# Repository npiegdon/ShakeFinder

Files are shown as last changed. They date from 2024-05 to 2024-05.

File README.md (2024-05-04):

# ShakeFinder
## A low-cost, high-sensitivity vibration sensor

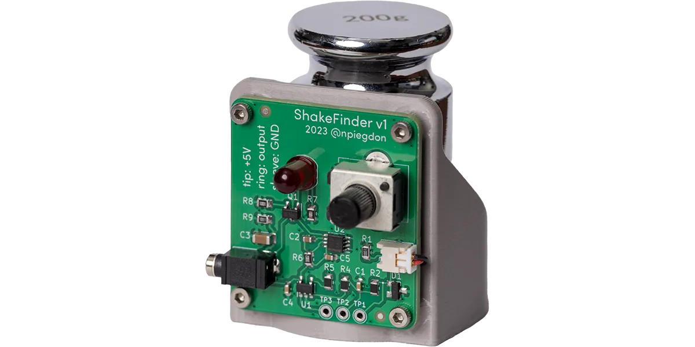
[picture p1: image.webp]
ShakeFinder (https://www.youtube.com/watch?v=hmemnF16wfw)


**Watch the [design video](https://www.youtube.com/watch?v=hmemnF16wfw) on YouTube!**

ShakeFinder is based on [David Houlding's](https://davidhoulding.blogspot.com/2014/02/high-sensitivity-vibration-sensor-using.html) vibration sensor with a number of improvements.  The most notable is an open-drain output so it can be connected to non-5V microcontrollers (like Raspberry Pi) easily.

This sensor was created for use with my homemade 8mm film scanner, the [ReelSlow8](https://forums.kinograph.cc/t/the-reelslow8-film-scanner/2491).

Sample code is provided for Arduino Uno.

## Bill of Materials

| Part | Value | Package/Notes | Link |
| --- | --- | --- | --- |
| Calibration weight | 200g | lowest-grade | [Amazon](https://www.amazon.com/dp/B0BLNHJLXJ) |
| Piezo element | 35mm disc | generic | [Amazon](https://www.amazon.com/dp/B084KHH7B6) |
| 2x1 PicoBlade connector (optional) | for the piezo element | Molex WM1720-ND for connector, 900-0500588020CT-ND for pins | |
| 2x1 PicoBlade socket (optional) | for the PCB | Molex WM1742-ND | |
| 2.5mm TRS jack | through-hole, right angle | SJ1-2503A | [DigiKey](https://www.digikey.com/en/products/detail/cui-devices/SJ1-2503A/738680) |
| Double-diode | ~0.5V drop at no current | BAV99, SOT-23 | [DigiKey](https://www.digikey.com/en/products/detail/nexperia-usa-inc/BAV99-235/1232158) |
| front end op-amp | Single supply, rail-to-rail, Vss-1 / Vdd+1 | MCP6001T, SOT-23-5 | [DigiKey](https://www.digikey.com/en/products/detail/microchip-technology/MCP6001T-I-OT/551760) |
| Potentiometer | Upright, TH, 100k, Log | PTV09A-4015U-A104 | [DigiKey](https://www.digikey.com/en/products/detail/bourns-inc/PTV09A-4015U-A104/6153483) |
| Retriggerable Monostable | SM8 is $0.10 more, but easier to hand-solder | SN74LVC1G123DCTR, 8SSOP (SM8) | [DigiKey](https://www.digikey.com/en/products/detail/texas-instruments/SN74LVC1G123DCTR/863597) |
| Output N-ch FET | This one has nice characteristics | AOSS32136C | [DigiKey](https://www.digikey.com/en/products/detail/alpha-omega-semiconductor-inc/AOSS32136C/11567433) |
| C1 | 10n | 0603 jellybean | |
| C2 | 1u | 0603 jellybean | |
| C3 | 10u | 1206 jellybean | |
| C5, C4 | 100n | 0603 jellybean | |
| D2 | red (or whatever) | 5mm through-hole jellybean | |
| R1, R9 | 100k | 0805 jellybean | |
| R2, R4, R5 | 10k | 0805 jellybean | |
| R7, R8 | 1k | 0805 jellybean | |
| R6 | Anywhere from 10k to 100k* | 0805 jellybean | |

\* The schematic lists 10k for R6.  The YouTube video demonstrates R6 at 33k.  The value of this resistor controls the length of the pulse.  Using 100k for R6 would cause even less chatter on the output.  Choose whatever you like here.  50k might be a reasonable place to start.

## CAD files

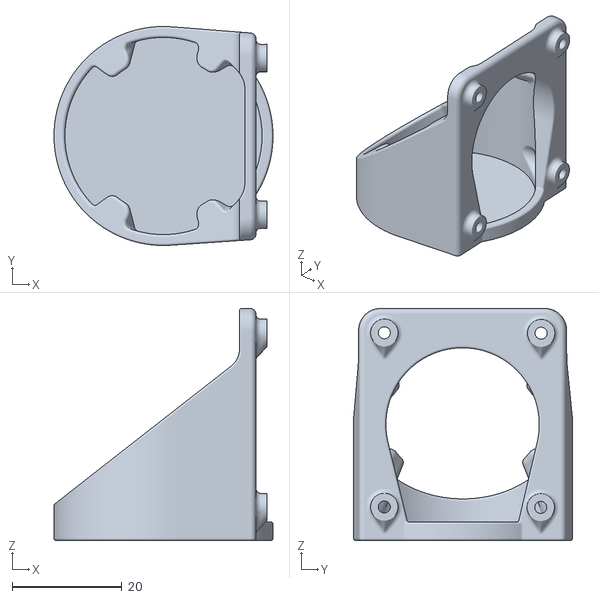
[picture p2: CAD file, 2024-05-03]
enclosure.stl
40.0 x 40.0 x 42.4

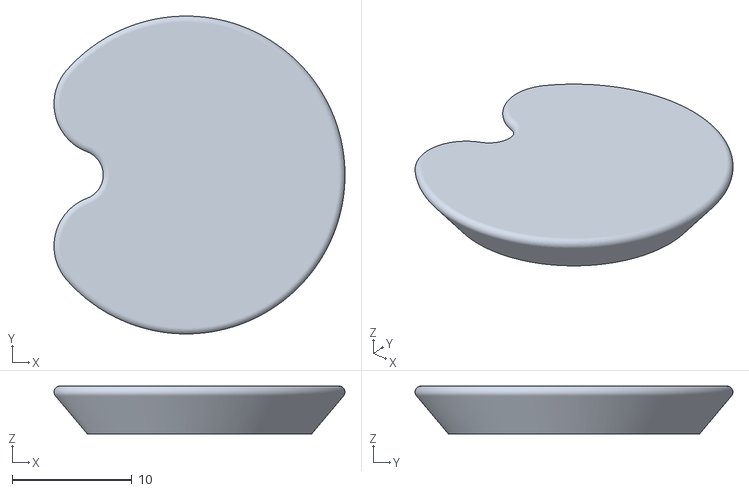
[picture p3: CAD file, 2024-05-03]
pedestal.stl
24.3 x 26.6 x 4.00

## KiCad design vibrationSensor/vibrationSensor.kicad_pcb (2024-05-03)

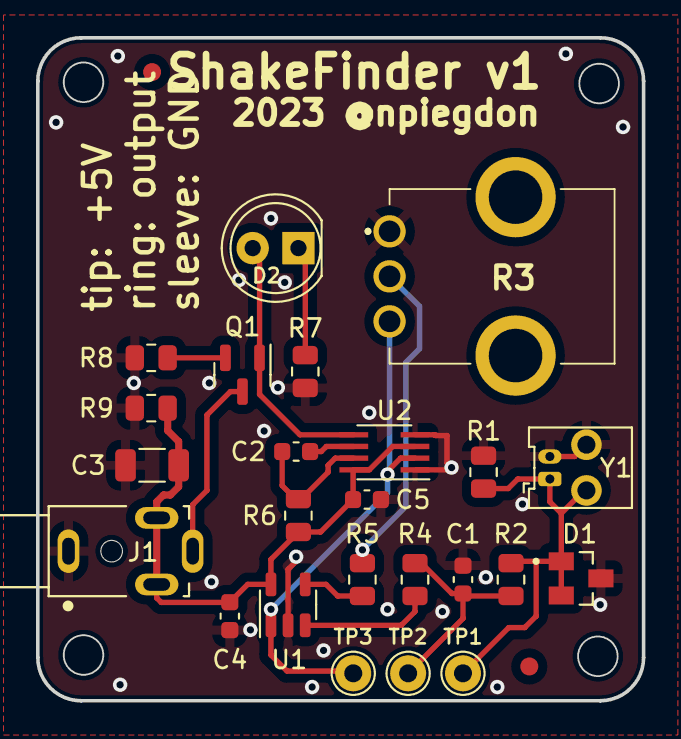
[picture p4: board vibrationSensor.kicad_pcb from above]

Board: 2 copper layers, 33.7 x 36.8 mm, 27 parts (0 on the bottom side), 14 nets.

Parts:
C1: 10n; C_0603_1608Metric
C2: 1u; C_0603_1608Metric
C3: 10u; C_1206_3216Metric
C4, C5: 100n; C_0603_1608Metric
D1: BAV99; DIO_BAV99
D2: RED; LED_D5.0mm_IRGrey
FID1, FID2: Fiducial; Fiducial_1mm_Mask2mm
J1: 2.5mm TRS; CUI_SJ1-2503A
J2: Conn_01x02_Pin; PinHeader_1x02_P2.54mm_Vertical
Q1: AOSS32136C; SOT-23
R1, R9: 100k; R_0805_2012Metric
R2, R4, R5, R6: 10k; R_0805_2012Metric
R3: 100k; Bournes PTV09A4020UB104
R7, R8: 1K; R_0805_2012Metric
TP1: Crystal; TestPoint_THTPad_D2.0mm_Drill1.0mm
TP2: LPF; TestPoint_THTPad_D2.0mm_Drill1.0mm
TP3: amp; TestPoint_THTPad_D2.0mm_Drill1.0mm
U1: MCP6001; SOT-23-5
U2: 74LVC1G123; SSOP-8_2.95x2.8mm_P0.65mm
Y1: Piezo; Molex_PicoBlade_53048-0210_1x02_P1.25mm_Horizontal

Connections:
+5V: C3.1, C4.1, C5.1, J1.2, J1.3, R6.1, R9.1, U1.5 (V+), U2.3 (~CLR), U2.8 (VCC)
GND: C1.2, C3.2, C4.2, C5.2, D1.3, J1.1, J2.2, R1.2, R3.1, R7.2, R8.2, R9.2, U1.2 (V-), U2.1 (~A), U2.4 (GND), Y1.2
unnamed: C1.1, R2.2, R4.1, TP2.1
unnamed: D2.2 (A), Q1.1 (G), U2.5 (Q)
unnamed: D2.1 (K), R7.1
unnamed: D1.1, D1.2, J2.1, R1.1, R2.1, TP1.1, Y1.1
unnamed: Q1.2 (S), R8.1
unnamed: R3.2, R5.1
unnamed: R4.2, U1.3 (+)
unnamed: R5.2, U1.4 (-)
unnamed: R3.3, TP3.1, U1.1, U2.2 (B)
unnamed: C2.2, U2.6 (Cext)
unnamed: C2.1, R6.2, U2.7 (RCext)
out: J1.4, Q1.3 (D)

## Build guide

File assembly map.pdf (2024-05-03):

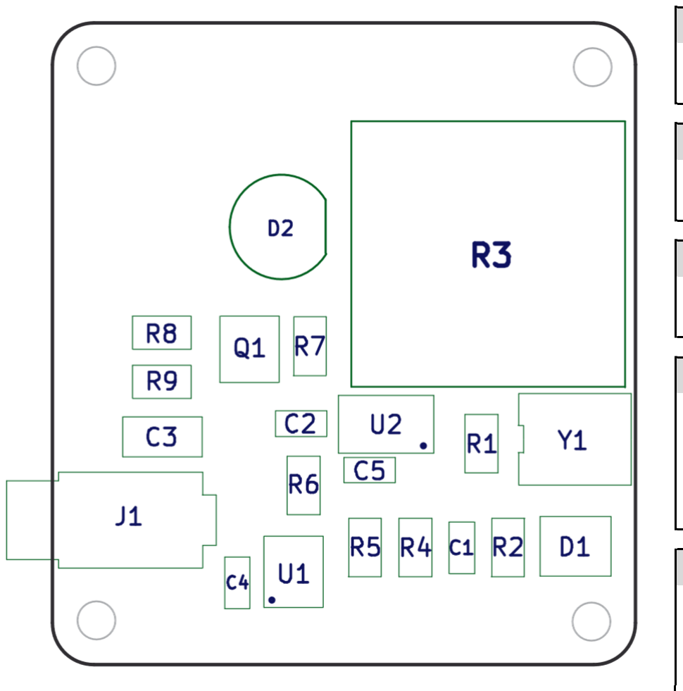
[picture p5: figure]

C1 | C2 | C3 | C4, C5
10n 0603 | 1u 0603 | 10u 1206 | 100n 0603
R1, R9 | R2, R4, R5 | R6 | R7, R8
100K 0805 | 10K 0805 | your choice
| | 10K to 100K | 1K 0805
U1 | U2 | Q1 | D1
SOT-23 MCP6001 | SSOP-8
| 74LVC1G123 | SOT-23
| | AOSS32136C | BAV99

# ShakeFinder v1 Assembly Map

R3

100K pot
PTV09A-4015U-A104

Y1

PicoBlade 53048-0210
or 1x2 pin header
or direct solder the disc

J1

2.5mm TRS
or direct solder

D2

5mm LED

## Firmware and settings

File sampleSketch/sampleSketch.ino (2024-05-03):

#include <util/atomic.h>

// Which pin is ShakeFinder's output connected to? (It
// should be one of the pins with an "INTx" interrupt.)
static constexpr int ShakeFinderPin = 3;

// This ISR will be called whenever ShakeFinder's output
// goes low (which means it detected vibration).
volatile bool shakeDetected = false;
static void ShakeISR() noexcept { shakeDetected = true; }

// Call this anytime you'd like to know whether shaking was
// detected since the last time you called this.  It acts as
// both the way to retrieve the value and the way to reset it.
bool ShookOrShakingWithReset()
{
  bool shook = false;
  ATOMIC_BLOCK(ATOMIC_RESTORESTATE)
  {
    shook = shakeDetected;
    shakeDetected = false;
  }

  const bool stillShaking = digitalRead(ShakeFinderPin) == 0;
  return shook || stillShaking;
}

void setup()
{
  // INPUT_PULLUP enables the internal 50k pull-up that
  // ShakeFinder needs for its open-drain output.
  pinMode(ShakeFinderPin, INPUT_PULLUP);

  // ShakeFinder pulls its output pin low whenever
  // shaking is detected, so we look for FALLING edges.
  attachInterrupt(digitalPinToInterrupt(ShakeFinderPin), ShakeISR, FALLING);

  // Just for this demo.
  pinMode(LED_BUILTIN, OUTPUT);
}

void loop()
{
  // For now, let's just echo ShakeFinder's state by reading
  // its output directly.
  digitalWrite(LED_BUILTIN, !digitalRead(ShakeFinderPin));

  // You can do work here and call ShookOrShakingWithReset as
  // infrequently as you like.  The general pattern when you
  // need to do a critical task will look something like this:

  //
  // do
  // {
  //   // Wait until things aren't moving.
  //   while (ShookOrShakingWithReset()) { }
  //
  //   // TODO: Do your important, long-running task here.
  //
  // } while (!ShookOrShakingWithReset());
  //

  // The first, empty while() loop busy-waits until shaking
  // isn't detected.  The do-while loop will keep repeating
  // your task until it was completed without any shaking.
}
